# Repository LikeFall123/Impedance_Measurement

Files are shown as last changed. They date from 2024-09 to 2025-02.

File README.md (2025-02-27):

# Impedance Measurement
Project laboratory excercise - BME 2023/24/2 semester

The STM32F407 MCU calculates the impedance of the selected passive component, by measuring the excitation signal and the response.

Used techniques:\
  -ADC + DMA\
  -Real time Fourier transform (armmath.h)\
  -Model based sine parameter estimation

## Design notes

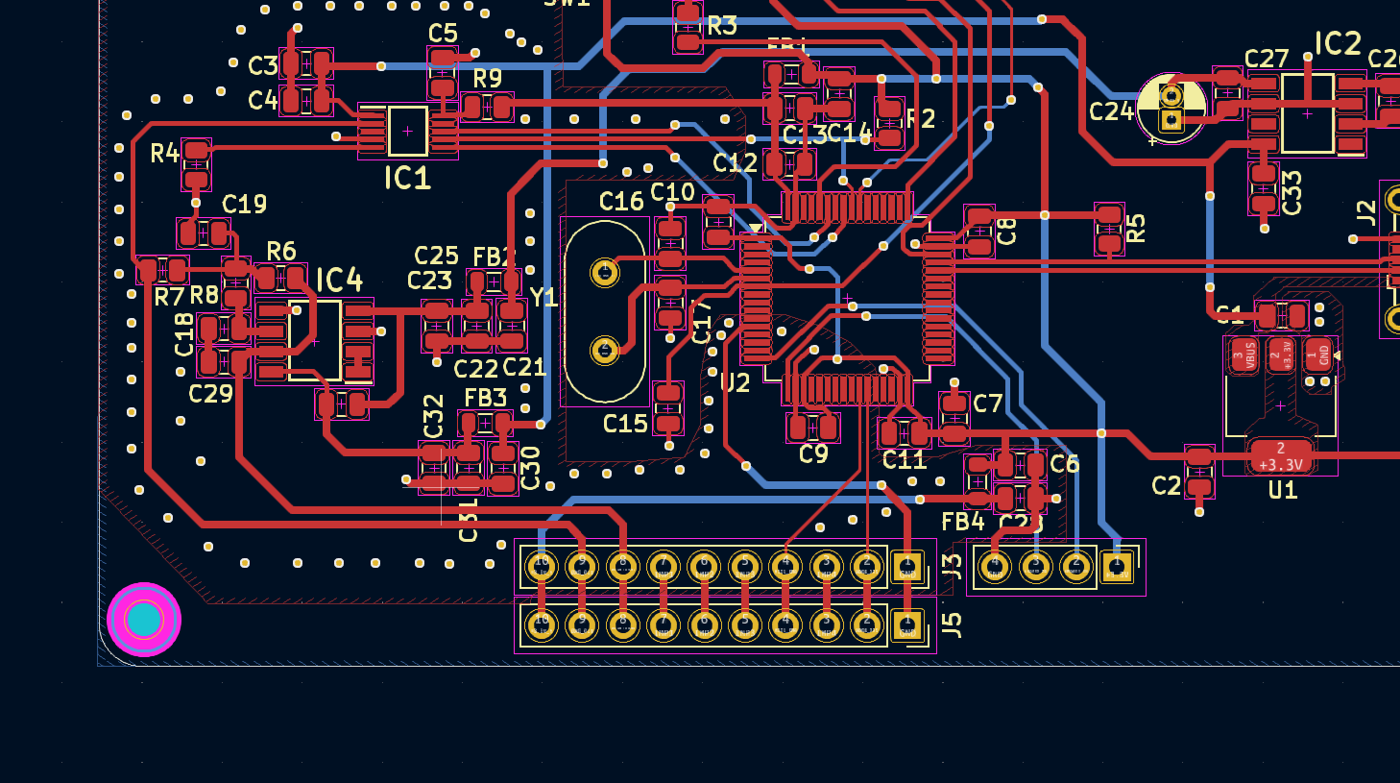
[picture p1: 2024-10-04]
prev_without_halfDC.png

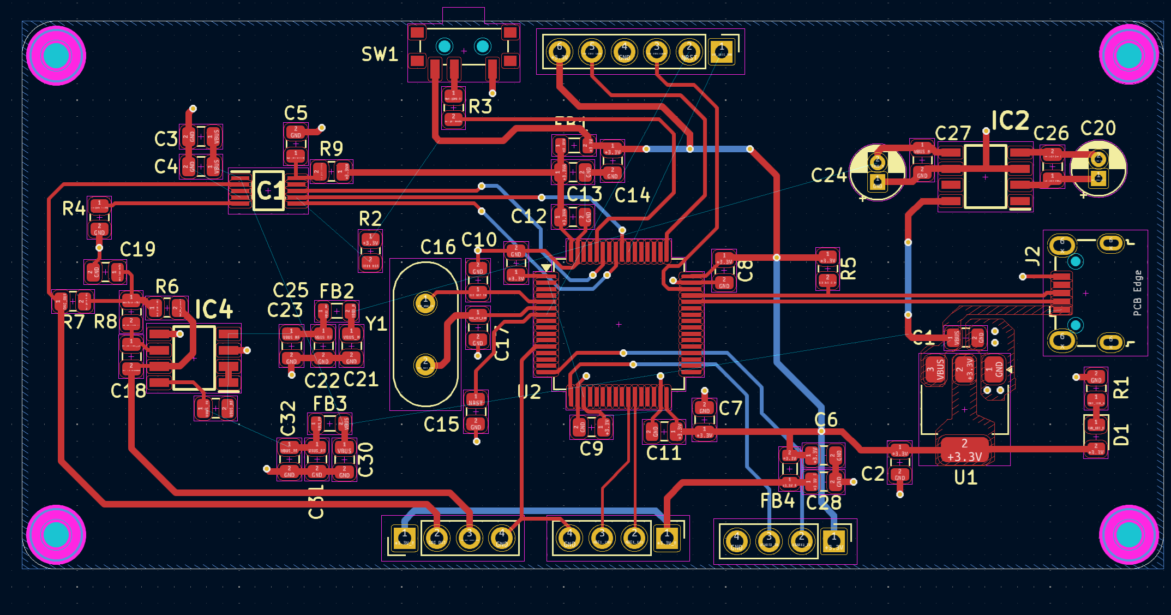
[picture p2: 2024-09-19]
Imp_meas_pcb.png

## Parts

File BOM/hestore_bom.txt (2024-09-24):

100.011.22	10	100 nF / 50V
100.011.24	10	10 nF / 50V
100.011.37	4	47 pF / 50V
100.011.45	10	SMD0805-10K-5%
100.011.58	10	SMD0805-1.5K-5%
100.014.02	4	220 uF / 16V
100.200.82	2	6,8 nF / 50V
100.255.15	1	14,3181 MHz
100.258.34	2	OF-SMD 2012 R
100.261.61	1	ZL201-40G (WWS40G)
100.282.00	1	MAX619
100.285.71	4	MC33202-SMD
100.301.63	15	1 uF / 16V
100.312.99	10	1K 1%
100.343.20	1	330 nF / 16V
100.344.52	10	10 uF / 16V
100.354.99	1	AMS1117-3.3 (TS1117)
100.387.04	2	10118193-0001LF
100.405.85	1	STM32F103RCT6
100.420.63	2	SS12D00G2
100.447.32	4	GRM21BR60J226ME39K
100.459.95	10	SMD0805-3.3K-1%
Hiányzik a DAC!

Összesen: 7707 Ft

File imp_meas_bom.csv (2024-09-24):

Reference | Value | Datasheet | Footprint | Qty | DNP
C1,C2 | 22u | ~ | Capacitor_SMD:C_0805_2012Metric | 2
C3,C7 | 10u | ~ | Capacitor_SMD:C_0805_2012Metric | 2
C4,C8,C9,C10,C11,C15,C25 | 100n | ~ | Capacitor_SMD:C_0805_2012Metric | 7
C5 | 330n | ~ | Capacitor_SMD:C_0805_2012Metric | 1
C6,C13,C14,C21,C22,C26,C27,C28,C30,C31 | 1u | ~ | Capacitor_SMD:C_0805_2012Metric | 10
C12,C23,C32 | 10n | ~ | Capacitor_SMD:C_0805_2012Metric | 3
C16,C17 | 10p | ~ | Capacitor_SMD:C_0805_2012Metric | 2
C18,C19,C29 | 1n | ~ | Capacitor_SMD:C_0805_2012Metric | 3
C20,C24 | 150u | ~ | Capacitor_THT:CP_Radial_D4.0mm_P1.50mm | 2
D1 | LED | ~ | LED_SMD:LED_0805_2012Metric | 1
FB1,FB2,FB3,FB4 | 120R | ~ | Inductor_SMD:L_0805_2012Metric | 4
H1,H2,H3,H4 | MountingHole | ~ | MountingHole:MountingHole_2mm | 4
IC1 | DAC80501ZDGST | http://www.ti.com/lit/ds/symlink/dac60501.pdf | SamacSys_Parts:SOP50P490X110-10N | 1
IC2 | MAX660MX_NOPB | http://www.ti.com/lit/gpn/max660 | SamacSys_Parts:SOIC127P600X175-8N | 1
IC4 | MC33202DR2G | https://www.onsemi.com/pub/Collateral/MC33201-D.PDF | SamacSys_Parts:SOIC127P600X175-8N | 1
J1,J3,J5 | Conn_01x04_Pin | ~ | Connector_PinHeader_2.54mm:PinHeader_1x04_P2.54mm_Vertical | 3
J2 | USB_B_Micro | ~ | Connector_USB:USB_Micro-B_Wuerth_629105150521 | 1
J4 | Conn_01x06_Pin | ~ | Connector_PinHeader_2.54mm:PinHeader_1x06_P2.54mm_Vertical | 1
R1,R5 | 1k5 | ~ | Resistor_SMD:R_0805_2012Metric | 2
R2,R3,R4 | 10k | ~ | Resistor_SMD:R_0805_2012Metric | 3
R6,R7 | 3k3 | ~ | Resistor_SMD:R_0805_2012Metric | 2
R8 | 1k6 | ~ | Resistor_SMD:R_0805_2012Metric | 1
R9 | 1k | ~ | Resistor_SMD:R_0805_2012Metric | 1
SW1 | SW_SPDT | ~ | Button_Switch_THT:SW_Slide-03_Wuerth-WS-SLTV_10x2.5x6.4_P2.54mm | 1
U1 | AMS1117-3.3 | http://www.advanced-monolithic.com/pdf/ds1117.pdf | Package_TO_SOT_SMD:SOT-223-3_TabPin2 | 1
U2 | STM32F401RCT6 | https://www.st.com/resource/en/datasheet/stm32f401rc.pdf | Package_QFP:LQFP-64_10x10mm_P0.5mm | 1
Y1 | Crystal | ~ | Crystal:Crystal_HC49-U_Vertical | 1

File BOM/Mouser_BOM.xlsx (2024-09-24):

 | IMP_MEAS_ICS
ICS
Mouser No | Mfr. No | Manufacturer | Customer No | Description | RoHS | Lifecycle | Order Qty. | Price(HUF) | Ext.: (HUF)
511-STM32F401RCT6 | STM32F401RCT6 | STMicroelectronics |  | ARM Microcontrollers - MCU Cost effective DSP FPU ARM CortexM4 MCU | RoHS Compliant |  | 1 | 1646,92Ft | 1646.92
595-DAC80501ZDGST | DAC80501ZDGST | Texas Instruments |  | Digital to Analog Converters - DAC True 16-bit, 1-ch, SPI/I2C, voltage-output DAC in WSON package with precision internal reference 10-VSSOP -40 to 125 | RoHS Compliant |  | 1 | 2903,78Ft | 2903.78
926-LM1117MPX3.3NOPB | LM1117MPX-3.3/NOPB | Texas Instruments |  | LDO Voltage Regulators 800MA LDO LINEAR REG | RoHS Compliant |  | 1 | 397,94Ft | 397.94
863-MC33202DR2G | MC33202DR2G | onsemi |  | Operational Amplifiers - Op Amps 1.8-12V Dual Rail to Rail -40 to 105 Cel | RoHS Compliant |  | 4 | 212,37Ft | 849.48
926-MAX660MX/NOPB | MAX660MX/NOPB | Texas Instruments |  | Switching Voltage Regulators SWITCHED CAPACITOR VOLTAGE CONVERTER | RoHS Compliant |  | 2 | 602,82Ft | 1205.64
649-10118193-0001LF | 10118193-0001LF | Amphenol |  | USB Connectors 5P MICRO USB TYPE B RECEPTACLE W/ PEGS | RoHS Compliant |  | 2 | 183,21Ft | 366.42
179-SLW-883935-2A-D | SLW-883935-2A-D | Same Sky |  | Slide Switches 8.8 x 3.9 x 3.5 mm, 2 mm Raised Slide Actuator, Right-Angle, Through Hole | RoHS Compliant | New Product | 2 | 161,15Ft | 322.3
 |  |  |  |  |  |  |  | Összesen: | 7692.48
Mouser No | Mfr. No | Manufacturer | Customer No | Description | RoHS | Lifecycle | Order Qty. | Price(HUF) | Ext.: (HUF)
623-2508051217Y0 | 2508051217Y0 | Fair-Rite |  | Ferrite Beads MultLyr Chip Bead 120 OHM 0805 300mA | RoHS Compliant |  | 6 | 36,64Ft | 219.6
695-HC49US-143-U | HC-49/U-S14318180ABJB | Citizen |  | Crystals 14.31818MHz 18pF HC49S THROUGH HOLE | RoHS Compliant |  | 2 | 197,79Ft | 395.4
603-AC0805JR-071K6L | AC0805JR-071K6L | YAGEO |  | Thick Film Resistors - SMD 1.6kOhms 1/8W 0805 5 % AEC-Q200 Standard Power Version | RoHS Compliant By Exemption |  | 10 | 9,46Ft | 94
652-CR0805JW-102ELF | CR0805-JW-102ELF | Bourns |  | Thick Film Resistors - SMD 1K 5% | RoHS Compliant By Exemption |  | 10 | 4,73Ft | 47
652-CR0805JW-332ELF | CR0805-JW-332ELF | Bourns |  | Thick Film Resistors - SMD 3.3K 5% | RoHS Compliant By Exemption |  | 10 | 4,73Ft | 47
71-CRCW0805J-1.5K-E3 | CRCW08051K50JNEA | Vishay |  | Thick Film Resistors - SMD 1/8watt 1.5Kohms 5% 200ppm | RoHS Compliant By Exemption |  | 10 | 7,88Ft | 78
71-CRCW0805J-10K-E3 | CRCW080510K0JNEA | Vishay |  | Thick Film Resistors - SMD 1/8watt 10Kohms 5% 200ppm | RoHS Compliant By Exemption |  | 10 | 7,49Ft | 74
187-CL21B104KACNNWC | CL21B104KACNNWC | Samsung Electro-Mechanics |  | Multilayer Ceramic Capacitors MLCC - SMD/SMT 100?X7R +/-10% 25v 0 0805 | RoHS Compliant |  | 10 | 7,88Ft | 78
791-0805B334K160CT | 0805B334K160CT | Walsin |  | Multilayer Ceramic Capacitors MLCC - SMD/SMT 0.33uF +-10% 16V | RoHS Compliant |  | 1 | 42,55Ft | 42.5
187-CL21B105KPFNNNE | CL21B105KPFNNNE | Samsung Electro-Mechanics |  | Multilayer Ceramic Capacitors MLCC - SMD/SMT 1uF+/-10% 10V X7R 20 0805 | RoHS Compliant |  | 15 | 9,06Ft | 135
187-CL21A106KPFNNNF | CL21A106KPFNNNF | Samsung Electro-Mechanics |  | Multilayer Ceramic Capacitors MLCC - SMD/SMT 10uF+/-10% 10V X5R 2 0805 | RoHS Compliant |  | 10 | 16,55Ft | 165
80-C0805C100K5G | C0805C100K5GACTU | KEMET |  | Multilayer Ceramic Capacitors MLCC - SMD/SMT 50V 10pF C0G 0805 10% | RoHS Compliant |  | 2 | 36,64Ft | 73.2
187-CL21A226KQQNNNE | CL21A226KQQNNNE | Samsung Electro-Mechanics |  | Multilayer Ceramic Capacitors MLCC - SMD/SMT 22uF+/-10% 6.3V X5R 0805 | RoHS Compliant |  | 4 | 87,86Ft | 351.2
187-CL21B103KAANNNC | CL21B103KAANNNC | Samsung Electro-Mechanics |  | Multilayer Ceramic Capacitors MLCC - SMD/SMT 10nF+/-10% 25V X7R 2 0805 | RoHS Compliant |  | 10 | 7,49Ft | 74
140-RGA221M1EBK0811G | RGA221M1EBK-0811G | Lelon |  | Aluminium Electrolytic Capacitors - Radial Leaded 25V 220uF 105C 8x11.5mm | RoHS Compliant |  | 4 | 46,89Ft | 187.2
743-IN-S85CS5G | IN-S85CS5G | Inolux |  | Standard LEDs - SMD Green LED | RoHS Compliant |  | 2 | 91,80Ft | 183.6
187-CL21B103KAANNNC | CL21B103KAANNNC | Samsung Electro-Mechanics |  | Multilayer Ceramic Capacitors MLCC - SMD/SMT 10nF+/-10% 25V X7R 2 0805 | RoHS Compliant |  | 10 | 7,49 Ft | 74.9
 |  |  |  |  |  |  |  | Összesen: | 2319.6
 |  |  |  |  |  |  | =SZUM(J9:J15;J20:J36)

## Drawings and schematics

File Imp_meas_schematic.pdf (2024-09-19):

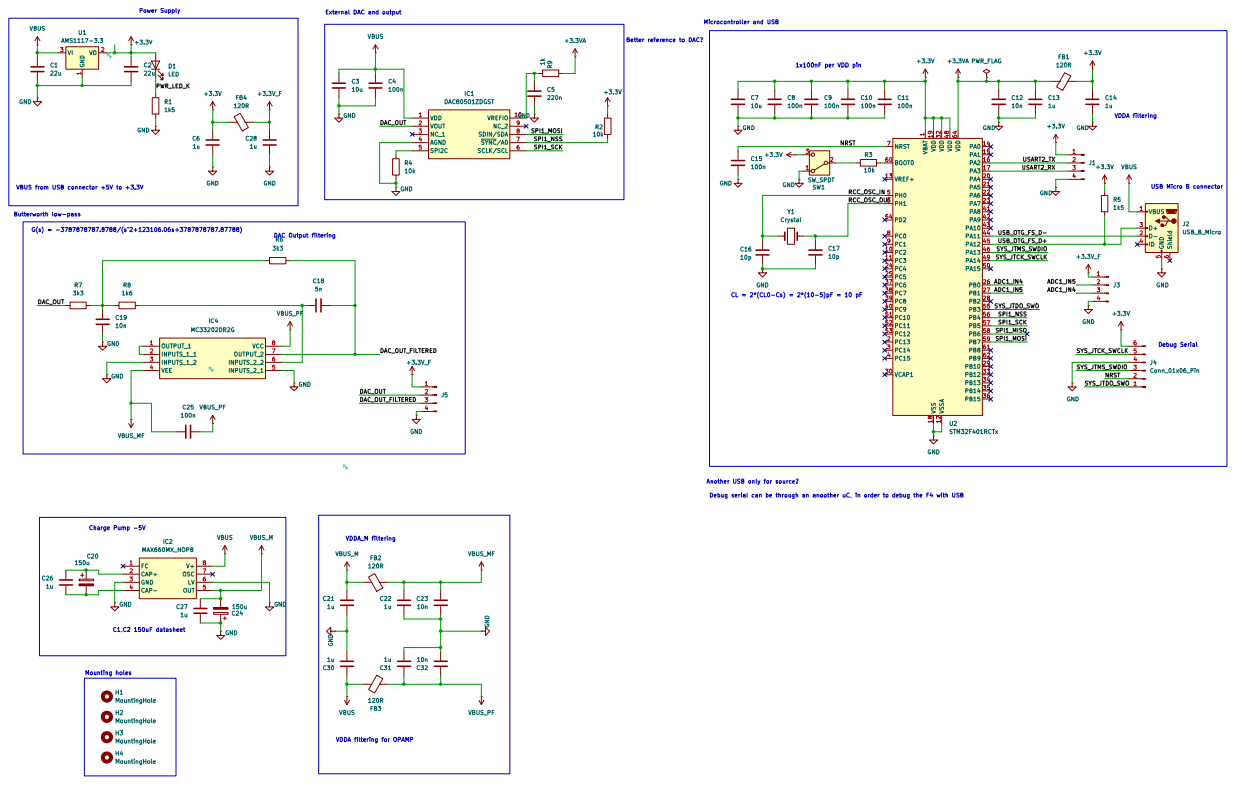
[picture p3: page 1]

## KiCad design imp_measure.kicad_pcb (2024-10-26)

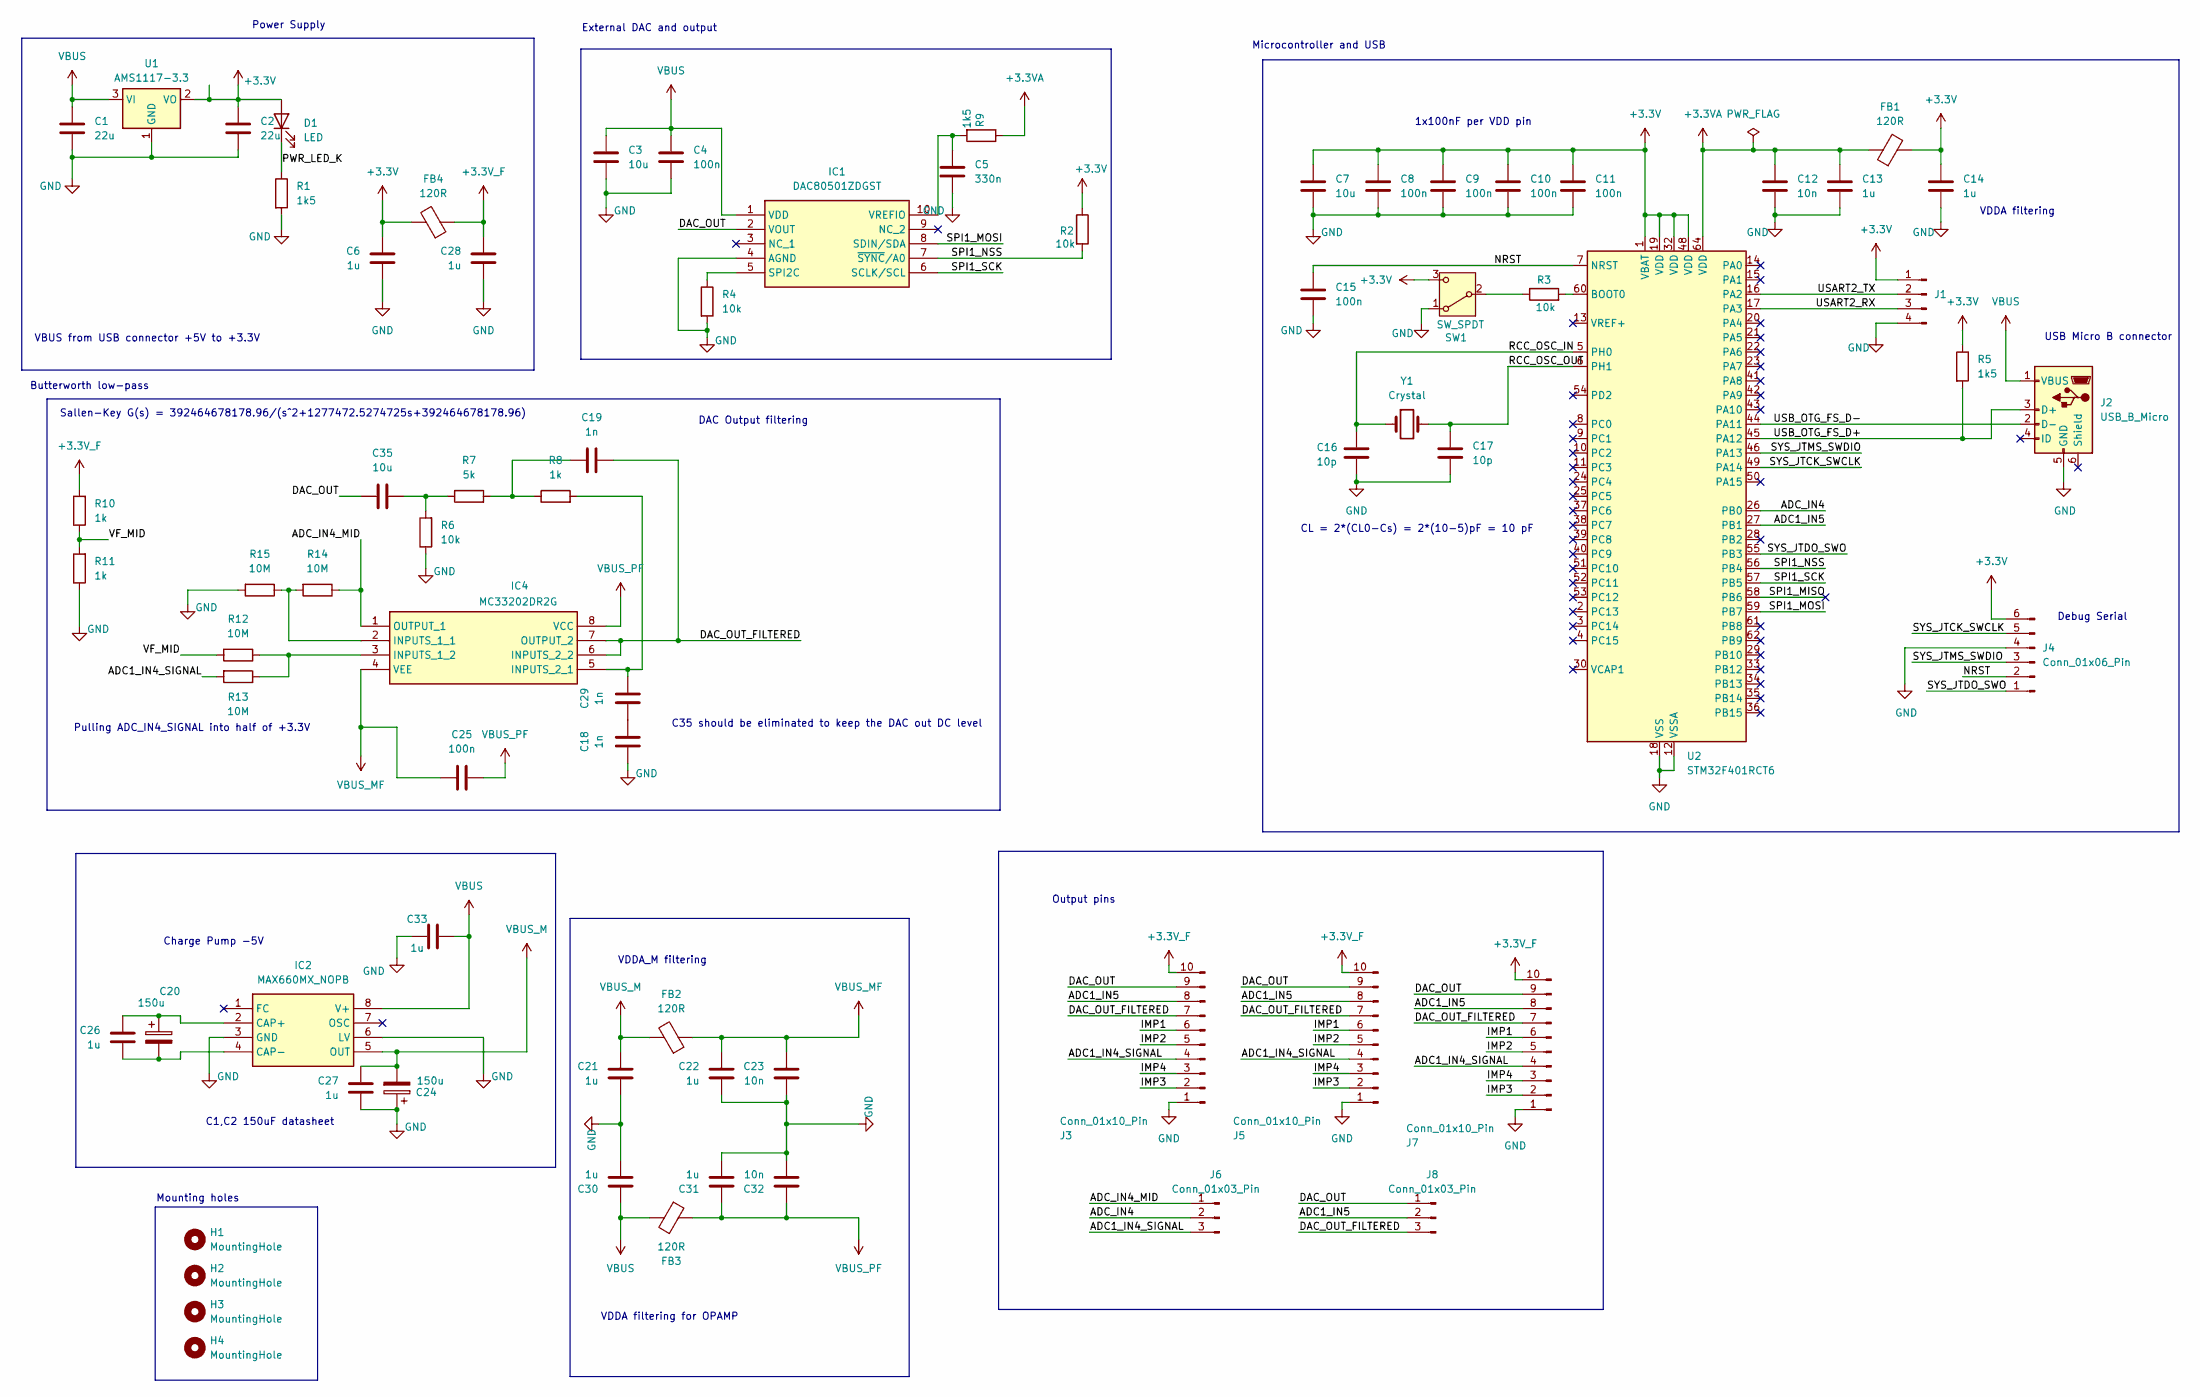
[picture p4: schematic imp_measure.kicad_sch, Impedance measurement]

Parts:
C1, C2: 22u; C_0805_2012Metric
C3, C7, C35: 10u; C_0805_2012Metric
C4, C8, C9, C10, C11, C15, C25: 100n; C_0805_2012Metric
C5: 330n; C_0805_2012Metric
C6, C13, C14, C21, C22, C26, C27, C28, C30, C31, C33: 1u; C_0805_2012Metric
C12, C23, C32: 10n; C_0805_2012Metric
C16, C17: 10p; C_0805_2012Metric
C18, C19, C29: 1n; C_0805_2012Metric
C20, C24: 150u; CP_Radial_D4.0mm_P1.50mm
D1: LED; LED_0805_2012Metric
FB1, FB2, FB3, FB4: 120R; L_0805_2012Metric
H1, H2, H3, H4: MountingHole; MountingHole_2mm
IC1: DAC80501ZDGST; SOP50P490X110-10N; Mouser Part Number 595-DAC80501ZDGST
IC2: MAX660MX_NOPB; SOIC127P600X175-8N; Mouser Part Number 926-MAX660MX/NOPB
IC4: MC33202DR2G; SOIC127P600X175-8N; Mouser Part Number 863-MC33202DR2G
J1: Conn_01x04_Pin; PinHeader_1x04_P2.54mm_Vertical
J2: USB_B_Micro; USB_Micro-B_Wuerth_629105150521
J3, J5, J7: Conn_01x10_Pin; PinSocket_1x10_P2.54mm_Vertical
J4: Conn_01x06_Pin; PinHeader_1x06_P2.54mm_Vertical
J6, J8: Conn_01x03_Pin; PinHeader_1x03_P2.54mm_Vertical
R1, R5, R9: 1k5; R_0805_2012Metric
R2, R3, R4, R6: 10k; R_0805_2012Metric
R7: 5k; R_0805_2012Metric
R8, R10, R11: 1k; R_0805_2012Metric
R12, R13, R14, R15: 10M; R_0805_2012Metric
SW1: SW_SPDT; SW_Slide-03_Wuerth-WS-SLTV_10x2.5x6.4_P2.54mm
U1: AMS1117-3.3; SOT-223-3_TabPin2
U2: STM32F401RCT6; LQFP-64_10x10mm_P0.5mm
Y1: Crystal; Crystal_HC49-U_Vertical

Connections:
+3.3V: C2.1, C6.1, C7.1, C8.1, C9.1, C10.1, C11.1, C14.1, D1.2 (A), FB1.2, FB4.2, J1.1, J4.6, R2.1, R5.1, SW1.3 (C), U1.2 (VO), U2.1 (VBAT), U2.19 (VDD), U2.32 (VDD), U2.48 (VDD)
+3.3VA: C12.1, C13.1, FB1.1, R9.1, U2.64 (VDD)
+3.3V_F: C28.1, FB4.1, J3.10, J5.10, J7.10, R10.2
/ADC1_IN4_SIGNAL: J3.4, J5.4, J6.3, J7.4, R13.2
/ADC1_IN5: J3.8, J5.8, J7.8, J8.2, U2.27 (PB1)
/ADC_IN4: J6.2, U2.26 (PB0)
/ADC_IN4_MID: IC4.1 (OUTPUT_1), J6.1, R14.1
/DAC_OUT: C35.1, IC1.2 (VOUT), J3.9, J5.9, J7.9, J8.1
/DAC_OUT_FILTERED: C19.2, IC4.6 (INPUTS_2_2), IC4.7 (OUTPUT_2), J3.7, J5.7, J7.7, J8.3
/IMP1: J3.6, J5.6, J7.6
/IMP2: J3.5, J5.5, J7.5
/IMP3: J3.2, J5.2, J7.2
/IMP4: J3.3, J5.3, J7.3
/NRST: C15.1, J4.2, U2.7 (NRST)
/PWR_LED_K: D1.1 (K), R1.1
/RCC_OSC_IN: C16.1, U2.5 (PH0), Y1.1
/RCC_OSC_OUT: C17.1, U2.6 (PH1), Y1.2
/SPI1_MISO: U2.58 (PB6)
/SPI1_MOSI: IC1.8 (SDIN/SDA), U2.59 (PB7)
/SPI1_NSS: IC1.7 (~SYNC/A0), R2.2, U2.56 (PB4)
/SPI1_SCK: IC1.6 (SCLK/SCL), U2.57 (PB5)
/SYS_JTCK_SWCLK: J4.5, U2.49 (PA14)
/SYS_JTDO_SWO: J4.1, U2.55 (PB3)
/SYS_JTMS_SWDIO: J4.3, U2.46 (PA13)
/USART2_RX: J1.3, U2.17 (PA3)
/USART2_TX: J1.2, U2.16 (PA2)
/USB_OTG_FS_D+: J2.3 (D+), R5.2, U2.45 (PA12)
/USB_OTG_FS_D-: J2.2 (D-), U2.44 (PA11)
/VF_MID: R10.1, R11.2, R12.2
GND: C1.2, C2.2, C3.2, C4.2, C5.2, C6.2, C7.2, C8.2, C9.2, C10.2, C11.2, C12.2, C13.2, C14.2, C15.2, C16.2, C17.2, C18.1, C21.2, C22.2, C23.2, C24.1, C27.2, C28.2, C30.2, C31.2, C32.2, C33.1, IC1.4 (AGND), IC2.3 (GND), IC2.6 (LV), J1.4, J2.5 (GND), J3.1, J4.4, J5.1, J7.1, R1.2, R4.2, R6.1, R11.1, R15.2, SW1.1 (A), U1.1 (GND), U2.12 (VSSA), U2.18 (VSS), U2.31 (VSS), U2.47 (VSS), U2.63 (VSS)
unnamed: C18.2, C29.1
unnamed: C19.1, R7.2, R8.1
unnamed: C35.2, R6.2, R7.1
unnamed: IC1.5 (SPI2C), R4.1
unnamed: C5.1, IC1.10 (VREFIO), R9.2
unnamed: C20.1, C26.1, IC2.2 (CAP+)
unnamed: C20.2, C26.2, IC2.4 (CAP-)
unnamed: IC4.2 (INPUTS_1_1), R14.2, R15.1
unnamed: IC4.3 (INPUTS_1_2), R12.1, R13.1
unnamed: C29.2, IC4.5 (INPUTS_2_1), R8.2
unnamed: R3.1, SW1.2 (B)
unnamed: R3.2, U2.60 (BOOT0)
VBUS: C1.1, C3.1, C4.1, C30.1, C33.2, FB3.2, IC1.1 (VDD), IC2.8 (V+), J2.1 (VBUS), U1.3 (VI)
VBUS_M: C21.1, C24.2, C27.1, FB2.2, IC2.5 (OUT)
VBUS_MF: C22.1, C23.1, C25.2, FB2.1, IC4.4 (VEE)
VBUS_PF: C25.1, C31.1, C32.1, FB3.1, IC4.8 (VCC)

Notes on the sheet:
VDDA filtering for OPAMP
VBUS from USB connector +5V to +3.3V
VDDA_M filtering
C1,C2 150uF datasheet
1x100nF per VDD pin
Pulling ADC_IN4_SIGNAL into half of +3.3V
DAC Output filtering
External DAC and output
CL = 2*(CL0-Cs) = 2*(10-5)pF = 10 pF
C35 should be eliminated to keep the DAC out DC level
Microcontroller and USB
Sallen-Key G(s) = 392464678178.96/(s^2+1277472.5274725s+392464678178.96)
Charge Pump -5V
Power Supply
Output pins
Mounting holes
USB Micro B connector
VDDA filtering
Butterworth low-pass
Debug Serial

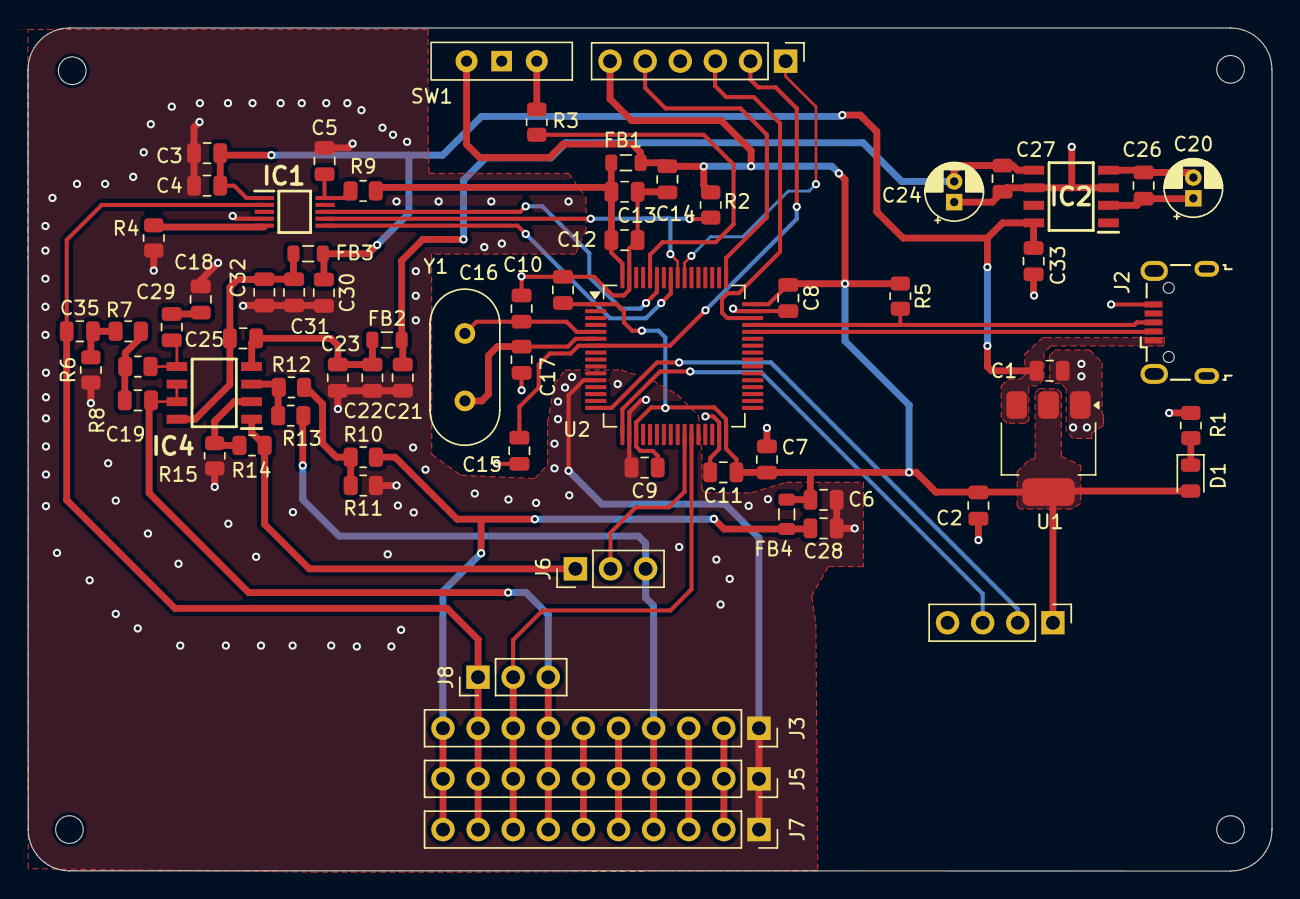
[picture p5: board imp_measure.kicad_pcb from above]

Board: 2 copper layers, 90.0 x 61.0 mm, 73 parts (0 on the bottom side), 45 nets.

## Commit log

2024-09-11 Add files via upload
    Initial schematic design in KiCad
    [imp_measure.kicad_pcb, imp_measure.kicad_sch]
2024-09-11 Add files via upload
    PDF of the schematic
2024-09-19 PCB design 1.0
    [imp_measure.kicad_pcb, imp_measure.kicad_sch]
2024-09-19 SCH pdf and PCB screenshot
2024-09-24 Ground fill for analog part
    [imp_meas_bom.csv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]
2024-09-24 Matlab and LTSpice simulation
    MATLAB simulation for the output filter. Quantized signal FFT.
    LTSpice model for DAC quantized outpu.
2024-09-24 Gerber changes
    [imp_measure-B_Cu.gbr, imp_measure-B_Mask.gbr, imp_measure-B_Paste.gbr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]
2024-10-04 PCB v1.2
    Changing the Multiple Feedback topology to Salen-Key.
    [imp_measure-B_Cu.gbr, imp_measure-B_Mask.gbr, imp_measure-B_Paste.gbr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]
2024-10-26 Forrasztáshoz
    [imp_measure-B_Cu.gbr, imp_measure-B_Mask.gbr, imp_measure-B_Paste.gbr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]
